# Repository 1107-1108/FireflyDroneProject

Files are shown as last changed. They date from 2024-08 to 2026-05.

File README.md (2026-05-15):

# Firefly Quadcopter drone

🛠️  Developing...

Any suggestions or bug report please contact [1107@siwg.top](mailto:1107@siwg.top)

Thanks a lot for support from @Li3_Fish(CN-Version Document Review) and @RT-TO(PID lib)!

## Project Structure

FireflyDroneProject/

│

├── FireflyDrone/

│   └── main/ 

│       ├── AttitudeCtrl.c Attitude Estimation

│       ├── FireflyDrone_main.c Main Control

│       ├── KalmanFilter.c Kalman Filter Algorithm

│       ├── mpu6050.c mpu6050 sensor support lib

│       ├── quaternion.c Quaternion Calculation lib

│       ├── pid.cpp PID contorl lib

|       └── FireflyLink.c Remote Control lib (Developing...)

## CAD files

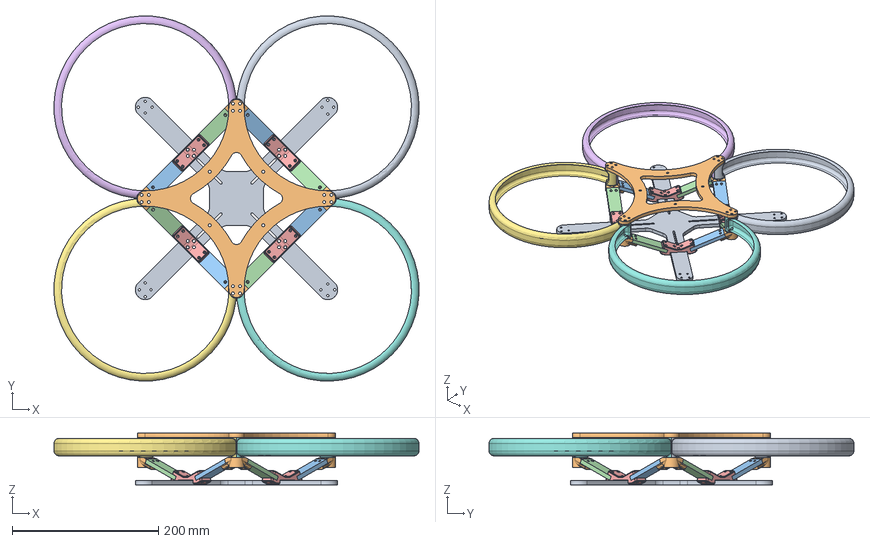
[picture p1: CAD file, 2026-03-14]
Model/Drone.step
499.8 x 499.8 x 70.6 mm
Component6(Mirror) x 4

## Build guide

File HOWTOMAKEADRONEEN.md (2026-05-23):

# How to make a drone

If anything wrong please contact [1107@siwg.top](mailto:1107@siwg.top).

Stay safe, have fun!

## Disclaimer

All content provided in this note(*How to Make a Drone*) is for learning, communication, and sharing purposes only, and should be used for reference only. Readers may use the content of this note for personal study, research, appreciation, and other non-commercial or non-profit purposes. At the same time, readers must comply with applicable open-source licenses and must not infringe upon the legitimate rights and interests of the note author or any related rights holders.

This note does not guarantee the completeness, accuracy, or timeliness of its content.

For the convenience of readers, this note may contain links to third-party websites. The content of such links does not represent the views of this note. By clicking these links, you may leave this note and enter third-party websites. This note and its author are not responsible for any risks, losses, or damages arising from third-party websites.

Some operations described in this note may involve safety risks. The note and its author shall not be held responsible for any injury, damage, or loss caused by improper operation or otherwise. Please proceed with caution and pay close attention to safety.

By continuing to read this note, you acknowledge and accept the above disclaimer and agree to assume all associated risks yourself.

The final interpretation of the above statements, within the limits permitted by law, belongs to this note and its author.

## Contributor

Author: 1107

## Content

1. Preparation for material
2. Tools&Techs for assemble
3. INS (Inertial Navigation System) design
4. FireflyLink Communication Protocol

## Preparation for Material

### 1.0 Introduction

This chapter introduces the option for material and MCU, aiming to find cheap, practial and fit suitable for the usage scenario material, as ~~**I am poor**~~

### 1.1 Options and Purchase for material

### Electronic Speed Controler(ECS)

We need ECS for transferring the control signal(Usually PWM) into the control of current in order to control the motor rotation.

**How do we Obtain parameter of ECS?**

Manufacturers usually provide

- Rated Voltage
- Continuous current
- BEC output
- ......

> RPM
> Voltage
> Current
> Temperature
> Consumption

### Brushless Mortor

Comparing to Brush Mortor, 

## INS (Inertial Navigation System) design

### MEKF — Multiplicative Extended Kalman Filter

The drone uses an MEKF to estimate 3D attitude by fusing gyroscope and accelerometer data. The state is a **quaternion** `q = [x, y, z, w]` (rotation from inertial to body frame), and a **3×3 covariance matrix `P`** over the attitude error vector. This avoids the singularity of a 4×4 quaternion covariance under the unit-norm constraint.

**Files:** `KalmanFilter.c` / `KalmanFilter.h`, quaternion math in `quaternion.c` / `quaternion.h`.

---

#### Data Structures

```c
typedef struct {
    double w, x, y, z;
} Quaternion;

typedef struct {
    Quaternion q;      // attitude quaternion
    double P[3][3];    // 3×3 error-state covariance
} MEKF;
```

#### Initialization: `mekf_init`

- `q = [0, 0, 0, 1]` — identity rotation (level, nose forward)
- `P = diag(1e-4, 1e-4, 1e-4)` — small initial uncertainty

---

#### Utility Functions

**`cross_product(a, b, res)`** — 3D cross product: `res = a × b`.

**`skew(vec, res)`** — builds the 3×3 skew-symmetric matrix:
```
        [  0   -vz   vy ]
[v]_× = [  vz   0   -vx ]
        [ -vy   vx   0  ]
```
Encodes cross product as matrix multiply: `[a]_× · b = a × b`.

**`matrix3_inverse(A, invA)`** — closed-form 3×3 inverse via cofactor expansion. Returns `false` if `|det| < 1e-12`.

**`errvec2quat(vec, dquat)`** — exponential map from `so(3)` to `SO(3)`:
```
θ = |vec|
if θ < 1e-8:  dq = [vec_x/2, vec_y/2, vec_z/2, 1]   (small-angle approx)
else:         dq = [sin(θ/2)·vec/θ, cos(θ/2)]
```
Result is always normalized.

---

#### Predict Step: `mekf_predict(model, omega, dt, Q)`

**Gyro integration:**
```
φ = ω · dt                 (body-frame rotation over timestep)
dq = errvec2quat(φ)        (convert to quaternion)
q_new = dq ⊗ q             (left-multiply: body-frame increment applied to attitude)
Normalize(q_new)
```

`quatMultiply(dquat, model->q)` computes `dquat * q` — left-multiplication applies a body-frame rotation correctly.

**Covariance propagation:**
```
P = P + Q
```

Uses `F ≈ I` approximation (valid for short timesteps). Q should be scaled by `dt²`: `Q = σ_gyro² · dt² · I₃`. The full `-[ω]_× P - P [ω]_×ᵀ` term is omitted as a common simplification.

---

#### Update Step: `mekf_update(model, z, v_I, R)`

The caller normalizes the accelerometer `z` and uses `v_I = [0, 0, 1]` (gravity in NED).

**1. Predicted measurement:**
```
A(q) = rotation matrix from quaternion:
       [ 1-2(y²+z²)   2(xy-zw)     2(xz+yw)  ]
       [ 2(xy+zw)     1-2(x²+z²)   2(yz-xw)  ]
       [ 2(xz-yw)     2(yz+xw)     1-2(x²+y²) ]

vB = A(q) · v_I           (predicted gravity in body frame)
```

**2. Innovation:**
```
y = z - vB
```

**3. Measurement Jacobian:**
```
H = -[vB]_×
```
Derivation: `A(δq)·v_I ≈ vB + [vB]_×·δθ`, so `y = -[vB]_×·δθ + noise`.

**4. Kalman gain:**
```
S = H·P·Hᵀ + R
If |S| < 1e-12 → skip update
K = P·Hᵀ·S⁻¹
```

**5. Attitude correction:**
```
a = K · y                 (error rotation vector)
dq = errvec2quat(a)
q_new = dq ⊗ q
Normalize(q_new)
```

**6. Covariance update (Joseph form):**
```
P = (I - KH)·P·(I - KH)ᵀ  +  K·R·Kᵀ
```
Then explicitly symmetrized: `P[i][j] = P[j][i] = ½(P[i][j] + P[j][i])`.

The Joseph form guarantees symmetry and positive-definiteness under floating-point roundoff.

---

#### Combined Step: `MEKF_step`

```c
void MEKF_step(MEKF *model, const double omega[3], double dt,
               const double z[3], const double v_I[3],
               const double Q[3][3], const double R[3][3])
```

Convenience wrapper — calls `mekf_predict` then `mekf_update`. The caller in `AttitudeCtrl.c` uses the two functions separately to normalize the accelerometer in between.

---

#### Data Flow

```
MPU6050 → raw accel/gyro → scale to physical units
                                │
                 ┌──────────────┴──────────────┐
                 ▼                              ▼
         omega (rad/s)              accel (normalized)
                 │                              │
                 ▼                              ▼
         mekf_predict(q, P)          mekf_update(q, P)
                 │                              │
                 └──────────┬───────────────────┘
                            ▼
                  updated quaternion q
                            │
                            ▼
                 atan2 formulas → roll, pitch, yaw (°)
                            │
                            ▼
                    nRF24L01 telemetry
```

---

#### Tuning Parameters

| Parameter | Meaning | Typical Value |
|---|---|---|
| `P_init` (diagonal) | Initial attitude uncertainty | `1e-4` |
| `Q` (diagonal) | Gyro process noise | `1e-6` ~ `1e-4` |
| `R` (diagonal) | Accelerometer measurement noise | `0.1` ~ `1.0` |

- **Higher Q** → trusts gyro more, smoother, slower convergence
- **Higher R** → trusts accelerometer less, less vibration-sensitive
- **Note:** Q should incorporate `dt²`; halving the loop period means quartering Q.

---

#### Euler Angle Extraction

From `AttitudeCtrl.c`, after MEKF produces `q`:

```
roll  = atan2(2(qw·qx + qy·qz), 1 - 2(qx² + qy²)) · 180/π
pitch = asin(2(qw·qy - qx·qz)) · 180/π
yaw   = atan2(2(qw·qz + qx·qy), 1 - 2(qy² + qz²)) · 180/π
```

The MEKF corrects roll and pitch via the gravity vector; yaw is unobservable from the accelerometer and relies on gyro integration alone (drift expected without a magnetometer).

## FireflyLink Communication Protocol

FireflyLink is a custom wireless protocol for the nRF24L01 module, featuring CRC16 error detection and Hamming(7,4) forward error correction to ensure reliable data transmission between drone and remote control.

**Files:** `FireflyLink.c` / `FireflyLink.h`

### Wire Format

nRF24L01 max payload = 32 bytes. FireflyLink packet structure:

```
Wire format (max 31 bytes for 13-byte payload):
[Header:1] [Seq:1] [Len:1] [Payload:N] [ECC:N] [CRC16:2]
  0xFD
```

| Field | Bytes | Description |
|---|---|---|
| Header | 1 | Fixed `0xFD`, identifies FireflyLink packet |
| Seq | 1 | Sequence number for drop detection |
| Len | 1 | Payload length N (max 13) |
| Payload | N | Data (attitude angles, battery, etc.) |
| ECC | N | Hamming(7,4) code, 1 ECC byte per payload byte |
| CRC16 | 2 | CRC16-CCITT over [Seq + Len + Payload + ECC] |

Max payload = 13 bytes: (32 − 5) / 2 = 13.

### Hamming(7,4) Encoding

Each payload byte is split into high nibble (bits[7:4]) and low nibble (bits[3:0]). Each nibble generates 3 parity bits:

- **Data bits:** 4 (d1 d2 d3 d4, mapping to nibble bits[3:0])
- **Parity bits:** 3 (p1 p2 p3)
  - p1 = d1 ⊕ d2 ⊕ d4
  - p2 = d1 ⊕ d3 ⊕ d4
  - p3 = d2 ⊕ d3 ⊕ d4

Both nibble parities are packed into 1 ECC byte:

```
ECC byte layout: [p1_hi p2_hi p3_hi p1_lo p2_lo p3_lo 0 0]
                 bit[5]  bit[4]  bit[3]  bit[2]  bit[1]  bit[0]
```

### Hamming(7,4) Decoding / Correction

The receiver computes a syndrome to locate and correct single-bit errors:

```
s1 = p1_received ⊕ p1_calculated
s2 = p2_received ⊕ p2_calculated
s3 = p3_received ⊕ p3_calculated
pos = (s3 << 2) | (s2 << 1) | s1
```

Syndrome-to-position mapping:

| s3:s2:s1 | Codeword Position | Action |
|---|---|---|
| 000 | No error | — |
| 001 / 010 / 100 | Parity bit error | Data correct, no fix needed |
| 011 | d1 (bit 3) | Flip data bit 3 |
| 101 | d2 (bit 2) | Flip data bit 2 |
| 110 | d3 (bit 1) | Flip data bit 1 |
| 111 | d4 (bit 0) | Flip data bit 0 |

### Data Flow

#### Transmit Side

```
Sensor data → fireflylink_init → fireflylink_pack → fireflylink_serialize → nrf24_send
                                     │                      │
                                     ▼                      ▼
                              Compute ECC + CRC      Serialize to wire bytes
```

#### Receive Side

```
nrf24_recv → fireflylink_parse → fireflylink_unpack → Application data
                                      │
                                      ▼
                              CRC check → Hamming repair → CRC recheck
```

### Error Correction Flow

1. Compute CRC16 of received data, compare against received CRC
2. CRC match → data intact, fast-path return (`FIREFLYLINK_OK`)
3. CRC mismatch → attempt Hamming single-bit correction
4. Recompute CRC after correction
5. CRC matches → correction successful, return number of bits corrected
6. Still mismatched → unrecoverable, return `FIREFLYLINK_ERR_CRC`

### API Reference

| Function | Description |
|---|---|
| `fireflylink_init(pkt, seq)` | Initialize packet, zero-fill and set sequence number |
| `fireflylink_pack(pkt, data, len)` | Pack data, compute ECC + CRC |
| `fireflylink_unpack(pkt, data_out, len_out)` | Unpack: CRC verify first, then Hamming repair on failure |
| `fireflylink_serialize(pkt, buf, size)` | Serialize to wire-format byte buffer |
| `fireflylink_parse(buf, size, pkt)` | Parse wire-format bytes into packet struct |
| `fireflylink_crc16(data, len)` | Direct CRC16-CCITT computation |
| `fireflylink_wire_size(pkt)` | Get wire-format byte count |

### Status Codes

| Return | Meaning |
|---|---|
| ≥ 0 | Success (unpack returns bits corrected) |
| `FIREFLYLINK_ERR_CRC (-1)` | CRC mismatch, data unrecoverable |
| `FIREFLYLINK_ERR_LEN (-2)` | Invalid payload length |
| `FIREFLYLINK_ERR_HEAD (-3)` | Wrong wire-format header byte |
| `FIREFLYLINK_ERR_SIZE (-4)` | Buffer size insufficient |

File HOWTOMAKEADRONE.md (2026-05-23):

# 教宁如何搓无人机

如果写错了请联系[1107@siwg.top](mailto:1107@siwg.top)，本人能力有限。

这也算是份学习记录吧。

请注意安全！

建议Typora食用，查看LaTeX公式效果更佳

有问题，但是不知道如何表达？看看这个! [智者提问手册](https://github.com/1107-1108/smartquestions/blob/master/智者提问手册.md)

## 免责声明

本教程（教宁如何搓无人机）（HOW TO MAKE A DRONE)提供的所有内容仅供学习、交流和分享用途，只供参考。阅读者可将本教程提供的内容用于个人学习，研究或欣赏，以及其他非商业性或营利性用途，但同时应遵守开源协议，不得侵犯本教程作者及相关权利人的合法权利。

本教程并不保证所有内容的完整性，准确性和及时性。

本教程内有为浏览者提供方便的第三方链接出现，链接内容并不代表本教程观点，若点击即可能将离开本教程进入第三方站点，本教程不为第三方站点带来的任何风险负责。

本教程内部分操作存在操作安全隐患，无论是否有不当操作造成的伤亡，本教程及其作者概不负责。请谨慎操作。

一经开始阅读，即表示您已经接受上述声明，需自行承担一切风险。

以上声明内容最终解释权在法律允许内归本教程及其作者所有。

## 贡献者

作者: 1107

校对：Li3_Fish

## 大纲

0. **相关法律**
1. 材料准备
2. 组装需要的技术
3. INS（惯性导航系统）设计

4. FireflyLink 通信协议设计

## 相关法律

无人机的测试以及飞行一定需要遵循当地法律！！！

请仔细阅读法律条例

如果你要带无人机电池上飞机请提前咨询航空公司，因为会有限制。

### 0.1 中华人民共和国相关法律

[中华人民共和国无人驾驶航空器飞行管理暂行条例](https://www.gov.cn/zhengce/content/202306/content_6888799.htm)

就比如，我17岁，事未成年人（大悲，想在国内飞无人机，所以根据第二章第十七条

> 《无人驾驶航空器飞行管理暂行条例》第二章第十七条
>
> 无民事行为能力人只能操控微型民用无人驾驶航空器飞行，限制民事行为能力人只能操控微型、轻型民用无人驾驶航空器飞行。无民事行为能力人操控微型民用无人驾驶航空器飞行或者限制民事行为能力人操控轻型民用无人驾驶航空器飞行，应当由符合前款规定条件的完全民事行为能力人现场指导。

我搓的无人机属于轻型无人机

> 《无人驾驶航空器飞行管理暂行条例》第六章第六十二条:
>
> 轻型无人驾驶航空器，是指空机重量不超过4千克且最大起飞重量不超过7千克，最大平飞速度不超过100千米/小时，具备符合空域管理要求的空域保持能力和可靠被监视能力，全程可以随时人工介入操控的无人驾驶航空器，但不包括微型无人驾驶航空器。

而轻型无人机

> 《无人驾驶航空器飞行管理暂行条例》第二章第十七条
>
> 操控微型、轻型民用无人驾驶航空器飞行的人员，无需取得操控员执照，但应当熟练掌握有关机型操作方法，了解风险警示信息和有关管理制度。

所以，在**适飞区**里飞我的无人机，首先需要在(UOM)[https://uom.caac.gov.cn/]里实名注册我的无人机，并且将实名登记标志黏贴到无人机上，然后需要个爹看着我飞。

### 0.2 大不列颠及北爱尔兰联合王国

[Introduction to drone flying and the UK rules | Civil Aviation Authority (caa.co.uk)](https://www.caa.co.uk/drones/rules-and-categories-of-drone-flying/introduction-to-drone-flying-and-the-uk-rules/)

根据英国法律，首先你需要遵循一下

> Key rules include:
>
> - Never fly more than 120m (400ft) above the surface
> - Always keep your drone or model aircraft in sight
> - Never fly in an airport’s flight restriction zone unless you have permission

**根据我的理解**，我的无人机重量肯定大于250克，所以我需要注册Operator ID和Flyer ID， 注册Operator ID的费用是11磅，并且需要通过在线理论考试（好像是开卷考所以不会很难）。

### 0.3 其他国家

请自行上网查找当地法律资料。

可以参考一下[全球各地区飞行安全法规合集（持续更新） (dji.com)](https://support.dji.com/help/content?customId=zh-cn03400009861&spaceId=34&re=CN&lang=zh-CN)

## 材料准备

### 1.0  引言

本章讲述对于材料和芯片的选择, 目的是选择实惠, 便宜, 符合使用场景的材料进行组装， 因为***孩子没钱了***

### 1.1 材料的选择与购买

**电调** 

为什么需要电调？因为电调的作用是把控制信号转为电流的大小来控制电机转速

电调的参数怎么看？ 电调会标上它能够提供的电流。

**无刷电机**

无刷电机相比有刷电机，取消了物理电刷，使用三相电供电，电流切换由外部控制，具有效率更高，寿命更长，运行更稳定等优势，所以这里采用无刷电机

但是~~无刷电机射桨更容易受伤~~

电机型号怎么看？无刷电机的型号，举个例子，叫2212，2808等，前两位是转子直径（胖不胖），后两位是转子高度（高不高）， *不是外壳*。高度和直径与电机功率成正比。

KV值是什么？KV是外加1v电压对应的每分钟空转转速。KV越小，扭力越大

无刷电机核心参数表

| 参数名 | 含义 | 性能影响 |
| --- | --- | --- |
| KV | RPM/V | 转速和响应速度 |
| 最大持续电流 | 电机长时间能承受最大电流(A) | ESC和电池规格 |
| 峰值电流 | 电机短时峰值承受能力 | |
| 推力 | 电机+桨叶输出最大推力(g) | 飞行器最大载重和加速 |
| 功率 | 电压*电流 | 供电需求 |
| 电机尺寸 | 定子直径+高度 | 决定扭矩 转速和负载  |

一般航拍无人机用中KV, 中尺寸电机(比如920KV, 2212)

**推重比**

推理通常基于厂商数据表给出。推重比 = 无人机总推力/无人机总重

推重比>2:1是最低要求。

**螺旋桨**

螺旋桨型号怎么看？型号也是数字，比如1045...., 前两位代表了直径，后两位代表桨叶的角度。

并且螺旋桨有正反桨，注意区分。

推荐桨叶尺寸9''-10'' for 2212

---------

以下材料都能从淘宝上购买

机架: 自己造, 白嫖学校的材料

      脚架            *4   自己造，白嫖学校的材料

电机: TODO

电调: 自己造，嘉立创

六轴姿态传感器: MPU6050 单价30

气压计: TODO

主控: ESP32-S3, 单价TODO

信号传输模块: TODO

桨叶: 自己造，白嫖学校的材料

BB响

**~~其实一点也不便宜~~**

### 1.2信息传输模块

这边暂时选择LORA，后面会进行补充

## 开始组装

### 2.0 引言

本章讲述组装无人机所需要的工具以及技术支持

### 2.1 工具

各种螺丝刀一套(尤其是六角螺丝刀和十字螺丝刀)

尖嘴钳， 剪线钳

电烙铁， 焊锡， 松香(或者别的助焊剂)

一根细细的, 结实的棍子

俩箱子外加一根又粗又长的棍子（也不能太粗, 毕竟要把无人机架在上面）

*是用来测试PID的，毕竟谁也不想测试无人机把自己测进医院吧

万用表一个

BB响一个

### 2.2 焊接

一般从淘宝买的传感器， 针脚都要自己焊接。这个时候电烙铁就十分有用了。最好选可以调节温度的那种电烙铁， 也不贵。

焊针脚的时候电烙铁焊锡靠近针脚， 看到焊锡融在针脚旁边的时候就焊好了(不难，反正网上教程一大把

这里还有个需要焊接的就是要把电源线焊到PCB板上， 电源线如果不挂锡可以用一下助焊剂(我用的松香)。

*焊完可以用万用表测试一下， 以防止虚焊。

*测试完可以用硅橡胶封一下，防止飞着飞着排线掉下来碰到别的触点， 反正挺便宜的

**~~虽然我焊的像史~~**

### 2.3 组装无人机

拧螺丝不用多说，可以在上螺丝的时候使用螺丝胶，防止飞在半空中震动导致螺丝松动， 电机也是如此。

电机与机架连接厂家送的是M3 * 8 的螺丝， 螺丝不要用太长的， 防止碰到电机内部线圈然后爆炸。

那上完螺丝胶怎么拆呢？用电烙铁热一下螺丝就行了。

### 2.4 电机与电调

电调的原理: 对线圈施加电流会产生磁场，依次激活每个线圈，转子就会旋转。我们不用具体了解无刷电机的原理，只需要知道他们是通过PWM信号的变化（占空比和频率）实现的。

如果只是想测试，可以去淘宝买个舵机测试仪。

电调在上电后需要重新设定油门行程，官方说明书上一般会说

> 开启遥控器，讲油门打到最高点，然后将电调上电，等待两秒，然后会有个提示音，听到后将油门推到最低，等待一秒，然后又有个提示音，是油门最低点确认音，之后系统准备就绪，可以起飞

确实，直接通过遥控器来校准最简单了

--------

**接线呢！！？他有一堆线怎么接啊？？？**

别急，电调有两端，一端是电源线+信号线 *(有红色线和黑色线的那边)*，另外一端是三根同样颜色的线,用来连接无刷电机。

>如果可行的话可以让店家先行焊好香蕉头，这样会好操作很多。

红黑线是电源线,分别对应电源的正负两级。剩下一根就是PWM信号线。拿好盈电调举例子，白色的是信号线，红色的是VCC(电源正极)，黑色的是GND(接地/电源负极)

然后另外一端三个同样颜色的线，随便往电机上接，然后如果转的方向错了随便调换两根的顺序即可。

## 飞控的设计

### 3.0 引言

很多人喜欢用stm32作为飞控MCU，而我喜欢esp32，所以用的esp32作为主控（选择主控因人而异，之前在利物浦大学甚至看到有拿树莓派3B当主控的，但是不推荐使用树莓派, 因为成本高且性能过剩）。本章介绍飞控的设计

### 3.1 基本概念

首先，我们需要知道几个概念——旋转矩阵，欧拉角，四元数。

#### 旋转矩阵

![Rotating Matrix][RotatingMatrix]

如图，坐标转换关系如下

$$ P_xA = P_xBcos(\alpha) - P_yBsin(\alpha) $$

$$ P_yA = P_xBsin(\alpha) + P_yBcos(\alpha) $$

$$ P_zA = P_zB $$

转换成矩阵形式就是

$$
\left [
\begin{matrix}
	P_xA \\
	P_yA \\
	P_zA 
\end {matrix}
\right]
 = 
\left [
\begin{matrix}
	cos(\alpha) & -sin(\alpha) & 0 \\
	sin(\alpha) & cos(\alpha) & 0 \\
	0 & 0 & 1
\end {matrix}
\right]
\times
\left [
\begin{matrix}
P_xB \\
P_yB \\
P_zB
\end {matrix}
\right ]
$$

绕x，y，z轴旋转的矩阵分别为：

$$
R_x(\theta) =
\left [
\begin{matrix}
1 & 0 & 0 \\
0 &  cos(\theta) & -sin(\theta) \\
0 & sin(\theta) & cos(\theta)
\end{matrix}
\right ]
$$

$$
R_y(\theta) = 
\left [
\begin{matrix}
cos(\theta) & 0 & sin(\theta) \\
0 & 1 & 0 \\
sin(\theta) & 0 & cos(\theta)
\end {matrix}
\right ]
$$

$$
R_z(\theta) = 
\left [
\begin{matrix}
cos(\theta) & sin(\theta) & 0 \\
-sin(\theta) & cos(\theta) & 0 \\
0 & 0 & 1
\end{matrix}
\right ]
$$

所以绕任意轴的姿态矩阵为 $$ R_x(\theta) \times R_y(\theta) \times R_z(\theta) $$

#### 欧拉角

百度百科说

> 欧拉角是用来唯一地确定定点转动刚体位置的三个一组独立角参量，由章动角θ、进动角ψ和自转角φ组成

有点难懂啊，这里拿图讲一讲

![Euler Angle][EulerAngle]

上图xyz是全局坐标，保持不变。XYZ是局部坐标，随物体姿态一起运动

旋转步骤: 物体绕全局z轴旋转 $\alpha $ 度

				然后绕全局x轴旋转$ \beta $度

				然后绕全局z轴旋转$\gamma$度

**弊端**

欧拉角有个坏处就是万向锁。一旦有个旋转轴为90度，那么第一次旋转和第三次旋转等价，从而使得旋转轴的自由度降低到两个，从而导致旋转结果出现异常。

#### 四元数

四元数的定义是
$$
q = a + bi + cj + dk (a, b, c, d \in \mathbb{R})
$$
也可以写成向量的模式
$$
\left [ \begin{matrix}
a \\
b \\
c \\
d \\
\end{matrix} \right ] 
= [s, v], 
v = \left [ \begin{matrix}
b \\
c \\
d \\
\end{matrix} \right ],
s, x, y, z \in \mathbb{R}
$$
其中，$i^2 = j^2 = k^2 = ijk $

四元数归一化就是
$$
||q|| = \sqrt{a^2+b^2+c^2+d^2}
$$
四元数的乘法也很简单
$$
q1 = a + bi + cj + dk
\\
q2 = e + fi + gj + hk
\\
q1q2 = (ae-bf-cg-dk)+(be+af-dg+ch)i+(ce+df+ag-bh)j+(de-cf+bg+ah)k
$$
也可以写成矩阵
$$
q1q2 = \left [ \begin{matrix}
a&-b&-c&-d \\
b&a&-d&c \\
c&d&a&-b \\
d&-c&b&a \\
\end{matrix} \right ]
\left [ \begin{matrix}
e \\
f \\
g \\
h \\
\end{matrix} \right ]
$$
**纯四元数**: $v = [0, v]$, 两个纯四元数乘法就是$vu = [-vu, vu], v=[0, v], u=[0, u]$

因为四元数不遵循交换律，所以

四元数的除法就是$pq^{-1}$或者$q^{-1}p$, 其中$q^{-1}$是逆四元数，且$qq^{-1} = q^{-1}q = 1(q \neq 0)$

**共轭**

给出四元数$q = a + bi + cj + dk$, 它的共轭是$q^* = a - bi - cj - dk$

### 3.2 姿态调解

思路: 这里采用的传感器是MPU6050, 包含两种数据: 角速度计和加速度计，因为如果单纯用角速度计数据容易因为各种因素而漂移，所以我们需要用滤波来实现稳定数据，通过加速度计数据来补偿漂移，从而得到平滑的数据

有很多种滤波，比如互补滤波，Mahony滤波，本文使用卡尔曼滤波。对于三维旋转物体而言Extended Multiplication Kalman Filter是最合适的卡尔曼滤波。

卡尔曼滤波分为两大部分，预测与更新

因为四元数不是线性的，所以我们把传感器数据视为真实数据乘一个小角误差
$$
q = \hat q \otimes \delta q
$$

#### 预测

给角速度$\omega = [\omega_x, \omega_y, \omega_z]$和同步时间 $dt$, 生成小角误差四元数`dquat`
$$
\phi = \omega \times dt
\\
\theta = |\phi|
\\
dquat = 

\left\{  
             \begin{array}{**lr**}  
             \omega = 1, x = 0.5 *\phi_x, y = 0.5*\phi_y, z = 0.5*\phi_z, if \hspace{0.3em} \theta \approx 0  \\
             \omega = cos(\theta / 2), x = \frac{\phi_x sin(\theta/2)}{\theta}, .....
             \end{array}  
\right.  
$$
更新四元数
$$
q \leftarrow q \otimes dquat
$$

#### 更新

1. 预测测量
   $$
   v_b = A * v_I
   $$

2. Innovation
   $$
   y = z - v_B
   $$
   
3. 构建测量矩阵
   $$
   H = -[v_B]_\times
   $$
   
4. 卡尔曼增益
   $$
   K = PH^T(HPH^T+R)^{-1}
   $$

5. 小角误差
   $$
   a = K_y
   $$

6. 小角修正四元数
   $$
   errquat = errvec2quat(a)
   $$
   
7. 更新四元数
   $$
   q \leftarrow q \otimes errquat
   $$
   
8. 更新协方差P
   $$
   P = (I - KH)P(I-KH)^T+KRK^T
   $$

### 3.3 控制理论

## FireflyLink 通信协议设计

FireflyLink 是为 nRF24L01 无线模块设计的自定义通信协议，包含 CRC16 校验和 Hamming(7,4) 前向纠错码，确保无人机与遥控器之间的数据传输可靠性。

**相关文件：** `FireflyLink.c` / `FireflyLink.h`

### 协议结构

nRF24L01 单次最大发送 32 字节，FireflyLink 包格式如下：

```
线格式（最大 31 字节，对应 13 字节有效载荷）：
[Header:1] [Seq:1] [Len:1] [Payload:N] [ECC:N] [CRC16:2]
  0xFD
```

| 字段 | 字节数 | 说明 |
|---|---|---|
| Header | 1 | 固定 `0xFD`，识别 FireflyLink 数据包 |
| Seq | 1 | 序列号，检测丢包 |
| Len | 1 | 有效载荷长度 N（最大 13） |
| Payload | N | 实际数据（姿态角、电池电压等） |
| ECC | N | Hamming(7,4) 纠错码，每字节载荷对应 1 字节 ECC |
| CRC16 | 2 | CRC16-CCITT 校验，覆盖 [Seq + Len + Payload + ECC] |

最大有效载荷 = 13 字节，因为 (32 - 5) / 2 = 13。

### Hamming(7,4) 编码

将每个载荷字节拆分为高半字节（bit[7:4]）和低半字节（bit[3:0]），分别进行编码：

- **数据位：** 4 位（d1 d2 d3 d4，对应半字节 bit[3:0]）
- **校验位：** 3 位（p1 p2 p3）
  - p1 = d1 ⊕ d2 ⊕ d4
  - p2 = d1 ⊕ d3 ⊕ d4
  - p3 = d2 ⊕ d3 ⊕ d4

两个半字节的校验码打包进 1 个 ECC 字节：

```
ECC 字节布局：[p1_hi p2_hi p3_hi p1_lo p2_lo p3_lo 0 0]
              bit[5]  bit[4]  bit[3]  bit[2]  bit[1]  bit[0]
```

### Hamming(7,4) 纠错

接收端通过伴随式（syndrome）定位并纠正单比特错误：

```
s1 = p1_received ⊕ p1_calculated
s2 = p2_received ⊕ p2_calculated
s3 = p3_received ⊕ p3_calculated
pos = (s3 << 2) | (s2 << 1) | s1
```

伴随式与错误位置对应关系：

| s3:s2:s1 | 码字位置 | 操作 |
|---|---|---|
| 000 | 无错误 | — |
| 001 / 010 / 100 | 校验位错误 | 数据正确，无需纠正 |
| 011 | d1（bit 3） | 翻转数据位 3 |
| 101 | d2（bit 2） | 翻转数据位 2 |
| 110 | d3（bit 1） | 翻转数据位 1 |
| 111 | d4（bit 0） | 翻转数据位 0 |

### 数据流

#### 发送端

```
传感器数据 → fireflylink_init → fireflylink_pack → fireflylink_serialize → nrf24_send
                                     │                      │
                                     ▼                      ▼
                             计算 ECC + CRC           序列化为线格式
```

#### 接收端

```
nrf24_recv → fireflylink_parse → fireflylink_unpack → 应用层数据
                                      │
                                      ▼
                              CRC 校验 → Hamming 纠错 → CRC 再校验
```

### 纠错流程

1. 计算接收数据的 CRC16，与收到的 CRC16 比对
2. CRC 匹配 → 数据完好，快速返回（`FIREFLYLINK_OK`）
3. CRC 不匹配 → 尝试 Hamming 单比特纠错
4. 纠错后重新计算 CRC
5. CRC 匹配 → 纠错成功，返回纠正的比特数
6. CRC 仍不匹配 → 不可恢复，返回 `FIREFLYLINK_ERR_CRC`

### API 参考

| 函数 | 说明 |
|---|---|
| `fireflylink_init(pkt, seq)` | 初始化数据包，清零并设置序列号 |
| `fireflylink_pack(pkt, data, len)` | 打包数据，计算 ECC + CRC |
| `fireflylink_unpack(pkt, data_out, len_out)` | 解包，先 CRC 校验，失败则 Hamming 纠错 |
| `fireflylink_serialize(pkt, buf, size)` | 序列化为线格式字节缓冲区 |
| `fireflylink_parse(buf, size, pkt)` | 从线格式字节解析为数据包结构体 |
| `fireflylink_crc16(data, len)` | 直接调用 CRC16-CCITT 计算 |
| `fireflylink_wire_size(pkt)` | 返回线格式字节数 |

### 状态码

| 返回值 | 含义 |
|---|---|
| ≥ 0 | 成功（unpack 返回纠正的比特数） |
| `FIREFLYLINK_ERR_CRC (-1)` | CRC 校验失败，数据不可恢复 |
| `FIREFLYLINK_ERR_LEN (-2)` | 载荷长度无效 |
| `FIREFLYLINK_ERR_HEAD (-3)` | 线格式包头错误 |
| `FIREFLYLINK_ERR_SIZE (-4)` | 缓冲区大小不足 |----------

[RotatingMatrix]:
[EulerAngle]:

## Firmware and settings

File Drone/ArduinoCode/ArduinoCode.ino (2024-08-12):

#include "MS5611.h"
#include <MPU6050_tockn.h>

int speed;

int motor1_speed;
int motor2_speed;
int motor3_speed;
int motor4_speed;

int MOTOR_1_PIN = 23;
int MOTOR_2_PIN = 22;
int MOTOR_3_PIN = 17;
int MOTOR_4_PIN = 16;

int MPU_PIN_SDA = 21;
int MPU_PIN_SCL = 19;

int GY_PIN_SDA = 27;
int GY_PIN_SCL = 26;

MS5611 MS5611(0x77);
MPU6050 mpu6050(Wire1);

char comdata[50];
long previousMillis = millis();     //上一次激活时间
long interval = 300; 


class PID {
public:
  PID(double P, double I, double D)
    : Kp(P), Ki(I), Kd(D), integral(0), err(0), err_last(0), set_val(0) {}

  void set_point(double set_val) {
    this->set_val = set_val;
  }

  double PIDAlgorithm(double actual_val) {
    err = set_val - actual_val;
    integral += err;
    
    double output = Kp * err + Ki * integral + Kd * (err - err_last);
    err_last = err;
    return output;
  }

private:
  double Kp, Ki, Kd;
  double integral;
  double err, err_last;
  double set_val;
};

PID pid(2.0, 0.1, 0.01);


void PWM(int PWMPin, int PWMValue){  // 模拟PWM；频率100Hz
  PWMValue += 1000;
  digitalWrite(PWMPin, HIGH);
  delayMicroseconds(PWMValue);
  digitalWrite(PWMPin, LOW);
  delayMicroseconds(10000 - PWMValue);
}

void MOTOR_INIT(int motorPins[], int size) {
  // 好盈电调初始化
  for(int i = 0; i <= 55; ++i) {
    for (int j = 0; j < size; ++j) {
      PWM(motorPins[j], 1000);
    }
  }
  for (int i = 0; i <= 100; ++i) {
    for (int j = 0; j < size; ++j) {
      PWM(motorPins[j], 0); //油门最小
    }
  }
  delay(2000);
}

float calculateAltitude(float currentPressure, float currentTemperature) {
  const float P0 = 101325;
  currentPressure = currentPressure * 100;
  float height = ((pow((P0 / currentPressure), (1 / 5.257)) - 1) * (currentTemperature + 273.15)) / 0.0065;
  return height;
}



float roll = 0, pitch = 0, yaw = 0;


float ax, ay, az, gx, gy, gz;

float q0 = 1, q1 = 0, q2 = 0, q3 = 0;

const float Kp_IMU = 26;
const float Ki_IMU = 0.0355;
float exInt = 0, eyInt = 0, ezInt = 0;
float norm;

const int SAMPLE_SIZE = 20;
int sampleIndex = 0;
float rollBuffer[SAMPLE_SIZE] = {0.0};
float pitchBuffer[SAMPLE_SIZE] = {0.0};
float current_roll, current_pitch;
int exp_roll, exp_pitch, exp_yaw;
float exp_altitude;
int up_num, down_num;

void IMU_update_quer(float gx, float gy, float gz, float ax, float ay, float az) {
  float vx, vy, vz;
  float ex, ey, ez;

  norm = sqrt(ax*ax + ay*ay + az*az);
  ax = ax / norm;
  ay = ay / norm;
  az = az / norm;

  vx = 2 * (q1 * q3 - q0 * q2);
  vy = 2* (q0 * q1 + q2 * q3);
  vz = q0 * q0 - q1 * q1 - q2 * q2 + q3 * q3;

  ex = (ay * vz - az * vy);
  ey = (az * vx - ax * vz);
  ez = (ax * vy - ay * vx);

  exInt = exInt + ex * Ki_IMU;
  eyInt = eyInt + ey * Ki_IMU;
  ezInt = ezInt + ez * Ki_IMU;

  gx = gx + Kp_IMU * ex + exInt;
  gy = gy + Kp_IMU * ey + eyInt;
  gz = gz + Kp_IMU * ez + ezInt;

  q0 = q0 + 0.001 * (-q1 * gx - q2 * gy - q3 * gz);
  q1 = q1 + 0.001 * (q0 * gx + q2 * gz - q3 * gy);
  q2 = q2 + 0.001 * (q0 * gy - q1 * gz + q3 * gx);
  q3 = q3 + 0.001 * (q0 * gz + q1 * gy - q2 * gx);

  norm = sqrt(q0 * q0 + q1 * q1 + q2 * q2 + q3 * q3);
  q0 = q0 / norm;
  q1 = q1 / norm;
  q2 = q2 / norm;
  q3 = q3 / norm;

  current_pitch = sin(-2 * q1 * q3 + 2 * q0 * q2) * 57.3;
  current_roll = atan2(2 * q2 * q3 + 2 * q0 * q1, -2 * q1 * q1 - 2 * q2* q2 + 1)* 57.3;

  rollBuffer[sampleIndex] = current_roll;
  pitchBuffer[sampleIndex] = current_pitch;

  sampleIndex = (sampleIndex + 1) % SAMPLE_SIZE;

  if (sampleIndex == 0) {
    float rollSum = 0.0;
    float pitchSum = 0.0;
    for (int i = 0 ; i < SAMPLE_SIZE; ++i) {
      rollSum += rollBuffer[i];
      pitchSum += pitchBuffer[i];
    }

    roll = rollSum / SAMPLE_SIZE;
    pitch = pitchSum / SAMPLE_SIZE;
  }
}

PID pid_roll(2.0, 0.1, 0.01);
PID pid_pitch(2.0, 0.1, 0.01);
PID pid_yaw(2.0, 0.1, 0.01);
PID pid_altitude(2.0, 0.1, 0.01);

float current_altitude;
float target_altitude = 0.0;



void update_motor_speeds(float exp_roll, float exp_pitch, float exp_yaw, float exp_altitude) {

  mpu6050.update();
  ax = mpu6050.getAccX();
  ay = mpu6050.getAccY();
  az = mpu6050.getAccZ();
  gx = mpu6050.getGyroX();
  gy = mpu6050.getGyroY();
  gz = mpu6050.getGyroZ();
  IMU_update_quer(gx, gy, gz, ax, ay, az);

  MS5611.read();
  current_altitude = calculateAltitude(MS5611.getPressure(), MS5611.getTemperature());

  pid_roll.set_point(exp_roll);
  pid_pitch.set_point(exp_pitch);
  pid_yaw.set_point(exp_yaw);
  pid_altitude.set_point(exp_altitude / 90 + current_altitude);


  double roll_control_signal = pid_roll.PIDAlgorithm(roll);
  double pitch_control_signal = pid_pitch.PIDAlgorithm(pitch);
  double yaw_control_signal = pid_yaw.PIDAlgorithm(yaw);
  double altitude_control_signal = pid_altitude.PIDAlgorithm(current_altitude);

  int base_speed = 150;
  motor1_speed = base_speed + roll_control_signal + pitch_control_signal - yaw_control_signal + altitude_control_signal;
  motor2_speed = base_speed - roll_control_signal + pitch_control_signal + yaw_control_signal + altitude_control_signal;
  motor3_speed = base_speed + roll_control_signal - pitch_control_signal + yaw_control_signal + altitude_control_signal;
  motor4_speed = base_speed - roll_control_signal - pitch_control_signal - yaw_control_signal + altitude_control_signal;

  motor1_speed = constrain(motor1_speed, 0, 1000);
  motor2_speed = constrain(motor2_speed, 0, 1000);
  motor3_speed = constrain(motor3_speed, 0, 1000);
  motor4_speed = constrain(motor4_speed, 0, 1000);

  PWM(MOTOR_1_PIN, motor1_speed);
  PWM(MOTOR_2_PIN, motor2_speed);
  PWM(MOTOR_3_PIN, motor3_speed);
  PWM(MOTOR_4_PIN, motor4_speed);

}

void processData(String comdata, int &exp_pitch, int &exp_roll, int &exp_yaw, int &other) {
  if (comdata.startsWith("Joystick:")) {
    int colonIndex = comdata.indexOf(':');
    if (colonIndex != -1) {
      String numbersPart = comdata.substring(colonIndex + 1);
      numbersPart.trim();

      int firstComma = numbersPart.indexOf(',');
      int secondComma = numbersPart.indexOf(',', firstComma + 1);
      int thirdComma = numbersPart.indexOf(',', secondComma + 1);

      exp_pitch = numbersPart.substring(0, firstComma).toInt(); // pitch
      exp_roll = numbersPart.substring(firstComma + 1, secondComma).toInt(); // roll
      exp_yaw = numbersPart.substring(secondComma + 1, thirdComma).toInt(); // yaw
      exp_altitude = numbersPart.substring(thirdComma + 1).toFloat(); // altitude
    }
  }
}

  

void setup() {
  pinMode(MOTOR_1_PIN, OUTPUT);
  pinMode(MOTOR_2_PIN, OUTPUT);
  pinMode(MOTOR_3_PIN, OUTPUT);
  pinMode(MOTOR_4_PIN, OUTPUT);
  pinMode(MPU_PIN_SDA, OUTPUT);
  pinMode(MPU_PIN_SCL, OUTPUT);


  Serial.begin(9600);
  Serial2.begin(9600,SERIAL_8N1,32, 33);
  Serial.println();
  Serial.println("Hello");
  Wire1.begin(MPU_PIN_SDA, MPU_PIN_SCL);
  Wire.begin(GY_PIN_SDA, GY_PIN_SCL);
  mpu6050.begin();
  mpu6050.calcGyroOffsets(true);


  int motorPins[] = {MOTOR_1_PIN, MOTOR_2_PIN, MOTOR_3_PIN, MOTOR_4_PIN};
  MOTOR_INIT(motorPins, 4);
  MS5611.begin();
  exp_altitude = calculateAltitude(MS5611.getPressure(), MS5611.getTemperature());
}

void send_data(String msg) {
  Serial2.print(msg);
}


void Receive_Data() {
  char endChar = '\n';
  int index = 0;

  while (Serial2.available() > 0 && index < sizeof(comdata) - 1) {
    char incomingChar = char(Serial2.read());

    if (incomingChar == endChar) {
      break;
    }

    comdata[index++] = incomingChar;
    delay(2);
  }
  comdata[index] = '\0';

  if (index > 0) {
    Serial.print("Received comdata: ");
    Serial.print(comdata);
    processData(comdata, exp_pitch, exp_roll, up_num, down_num);
  }
}


const unsigned long updateInterval = 30;
unsigned long previousUpdateTime = 0;

void loop() {
  unsigned long currentMillis = millis();

  if (currentMillis - previousUpdateTime >= updateInterval) {
    previousUpdateTime = currentMillis;

    if (Serial2.available()) {
      Receive_Data();
    }


    update_motor_speeds(exp_roll, exp_pitch, exp_yaw, exp_altitude);

    mpu6050.update();
    ax = mpu6050.getAccX();
    ay = mpu6050.getAccY();
    az = mpu6050.getAccZ();
    gx = mpu6050.getGyroX();
    gy = mpu6050.getGyroY();
    gz = mpu6050.getGyroZ();

    MS5611.read();
    float height = calculateAltitude(MS5611.getPressure(), MS5611.getTemperature());
    Serial.println(height);

    IMU_update_quer(gx, gy, gz, ax, ay, az);

    Serial.print("exp_pitch");
    Serial.print(exp_pitch);
    Serial.print("exp_roll");
    Serial.print(exp_roll);
    Serial.print("exp_altitude");
    Serial.print(exp_altitude);
    Serial.print("exp_yaw");
    Serial.println(exp_yaw);
  }
}

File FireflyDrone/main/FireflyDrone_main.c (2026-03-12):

#include <stdio.h>
#include "sdkconfig.h"
#include "freertos/FreeRTOS.h"
#include "freertos/task.h"
#include "esp_log.h"
#include "esp_mac.h"
#include "driver/i2c_master.h"
#include "mpu6050.h"
#include "FireflyDrone_main.h"
#include "AttitudeCtrl.h"
#include "quaternion.h"
#include "nrf24L01.h"
#include "driver/spi_master.h"

static const char *TAG = "board";

#define MKEF_FILTER_TIME_STEP           0.1 // second
#define PI                              3.1415926575

const double Q[3][3] = {
    {0.005, 0, 0},
    {0, 0.005, 0},
    {0, 0, 0.005}
};

const double R[3][3] = {
    {0.03, 0, 0},
    {0, 0.03, 0},
    {0, 0, 0.03}
};

Quaternion q = {1.0, 0.0, 0.0, 0.0};
double roll, pitch, yaw;
double gyro_sens = 131.0;


void mpu6050_task(void *arg) {
    i2c_master_bus_handle_t bus;
    i2c_master_dev_handle_t dev;

    i2c_master_init(&bus, &dev);
    mpu6050_init(dev);

    mpu6050_raw_dat raw;

    while(true) {
        mpu6050_read_raw(dev, &raw);
        // quatGyroUpdate(&q, raw.gx / gyro_sens * (PI / 180.0), raw.gy, raw.gz, 0.01);

        ESP_LOGI(TAG, "Accel: [%d %d %d], Gyro: [%d %d %d]",
                 raw.ax, raw.ay, raw.az,
                 raw.gx, raw.gy, raw.gz);
        
        MEKF_filter(MKEF_FILTER_TIME_STEP, Q, R, &raw, &roll, &pitch, &yaw);
        
        // quatToEulerFloat(q, &roll, &pitch, &yaw);
        
        ESP_LOGI(TAG, "roll:  %.2f, pitch:  %.2f, yaw:  %.2f]", roll, pitch, yaw);

        vTaskDelay(pdMS_TO_TICKS(100));
    }
}

void nrf24_task(void *arg) {
    nrf24_config_t cfg = {
        .pin_miso = 13,
        .pin_mosi = 11,
        .pin_sck = 12,
        .pin_csn = 10,
        .pin_ce = 9,
        .pin_irq = -1,
        .spi_host = SPI2_HOST,
    };

    uint8_t addr[5] = {'N', 'R', 'F', '2', '4'};


    ESP_ERROR_CHECK(nrf24_init(&cfg));
    ESP_ERROR_CHECK(nrf24_set_channel(76));
    ESP_ERROR_CHECK(nrf24_set_tx_addr(addr, 5));
    ESP_ERROR_CHECK(nrf24_set_rx_addr_p0(addr, 5)); 
    ESP_ERROR_CHECK(nrf24_print_regs());

    uint32_t cnt = 0;
    uint8_t tx_buf[32];

    while(true) {
        memset(tx_buf, 0, sizeof(tx_buf));
        snprintf((char *)tx_buf, sizeof(tx_buf), "hello %04lu", (unsigned long)cnt++);

        esp_err_t ret = nrf24_send(tx_buf, 32);
        if (ret == ESP_OK) {
            ESP_LOGI(TAG, "send ok: %s", tx_buf);
        } else {
            ESP_LOGE(TAG, "send failed: %s", esp_err_to_name(ret));
        }

        vTaskDelay(pdMS_TO_TICKS(1000));
    }
}

void app_main(void) {
    //xTaskCreate(mpu6050_task, "mpu6050_task", 4096, NULL, 5, NULL);
    xTaskCreate(nrf24_task, "nrf24_task", 4096, NULL, 5, NULL);
}

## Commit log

2024-07-14 update IMU
2024-07-15 Added Model of FCS, added details in md doc
    [飞控外壳.step]
2024-07-16 Updated model, Added parts in documents
    [飞控外壳-Base.stl, 飞控外壳-Lid.stl]
2024-07-29 Add tutorials
    [飞控外壳-Base.stl, 飞控外壳-Lid.stl]
2024-08-12 Increase PCB of brushed DC motor design
2024-09-02 Changed English Document
    [模版图纸08.13-1.dwg]
2025-12-07 Implement PID controller structure and functions
2025-12-07 Changed PID position
2026-02-07 Finished PID, nrf24I01 driver
2026-03-12 Finished nrf24L01 driver, fixed some bugs
    [main.c, nrf24L01.c]
2026-03-12 FireflyDrone PCB working
    [模版图纸08.13-1.dwg, 模版图纸08.13.dxf]
2026-03-14 Uploaded Drond model
    [Drone.step, 飞控外壳.step]
2026-03-15 Updated PCB
2026-03-16 Updated PCB design
2026-03-19 PCB 1.0 Done
2026-03-30 Fixed PCB bugs

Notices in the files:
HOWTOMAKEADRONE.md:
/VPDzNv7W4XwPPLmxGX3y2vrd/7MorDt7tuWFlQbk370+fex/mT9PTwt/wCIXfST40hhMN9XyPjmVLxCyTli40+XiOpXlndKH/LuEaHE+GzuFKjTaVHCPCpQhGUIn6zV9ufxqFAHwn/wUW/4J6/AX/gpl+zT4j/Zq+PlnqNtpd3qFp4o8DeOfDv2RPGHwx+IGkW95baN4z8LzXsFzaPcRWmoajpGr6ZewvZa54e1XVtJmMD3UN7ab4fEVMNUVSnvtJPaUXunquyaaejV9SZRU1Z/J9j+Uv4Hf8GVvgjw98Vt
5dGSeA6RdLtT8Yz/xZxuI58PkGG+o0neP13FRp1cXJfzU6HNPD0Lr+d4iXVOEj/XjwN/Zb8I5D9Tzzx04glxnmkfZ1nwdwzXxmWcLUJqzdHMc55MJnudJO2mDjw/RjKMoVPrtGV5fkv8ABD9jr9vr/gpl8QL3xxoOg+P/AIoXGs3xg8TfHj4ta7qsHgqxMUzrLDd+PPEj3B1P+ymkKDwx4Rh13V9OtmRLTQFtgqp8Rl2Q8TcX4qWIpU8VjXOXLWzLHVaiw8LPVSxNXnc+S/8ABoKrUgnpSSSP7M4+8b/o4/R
